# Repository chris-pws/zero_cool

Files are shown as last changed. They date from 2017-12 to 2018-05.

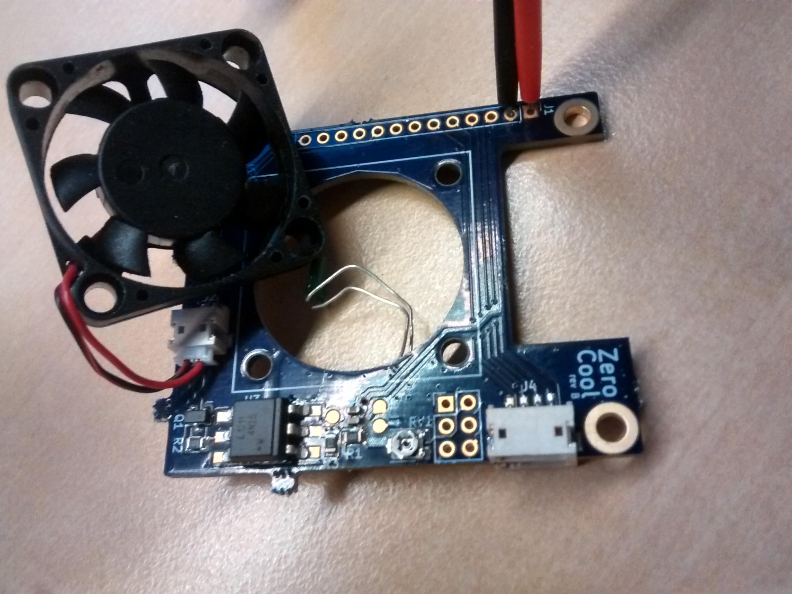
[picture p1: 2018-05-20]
IMG_20180520_031025.jpg

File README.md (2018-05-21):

# ZeroCool

Given that the Orange Pi Zero gets very hot when using all four cores and on-board wifi for any sustained period of time, I decided to create a fan controller that minimizes fan noise and respects the integrity of the wireless signal with respect to EMF noise. In keeping with the compact form factor of the Zero, this board shall mate securely with the SBC and cooling fan, and provide ready access to the H2+'s additional USB ports.

## Project notes

[Initial mechanical measurement and layout notes](https://github.com/cms-/zero_cool/blob/master/003.jpg)

[Rev B assembly and bring-up](https://github.com/cms-/zero_cool/blob/master/IMG_20180520_031025.jpg)

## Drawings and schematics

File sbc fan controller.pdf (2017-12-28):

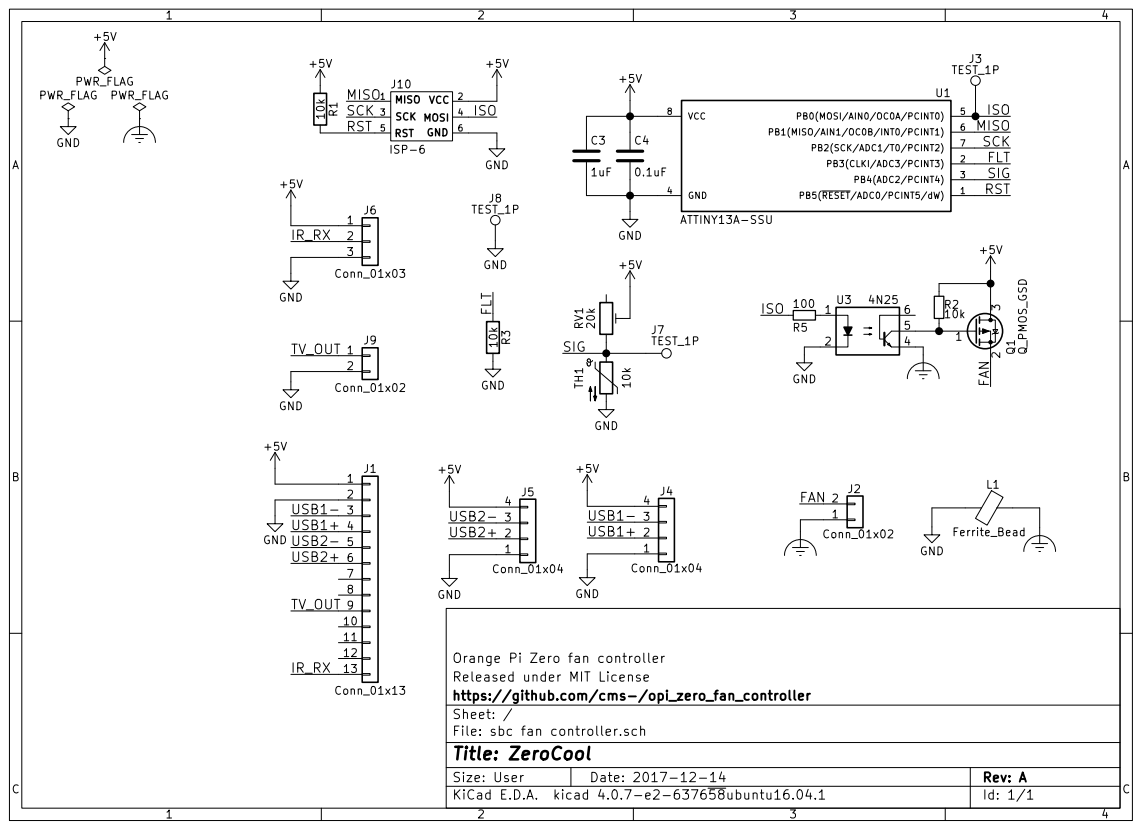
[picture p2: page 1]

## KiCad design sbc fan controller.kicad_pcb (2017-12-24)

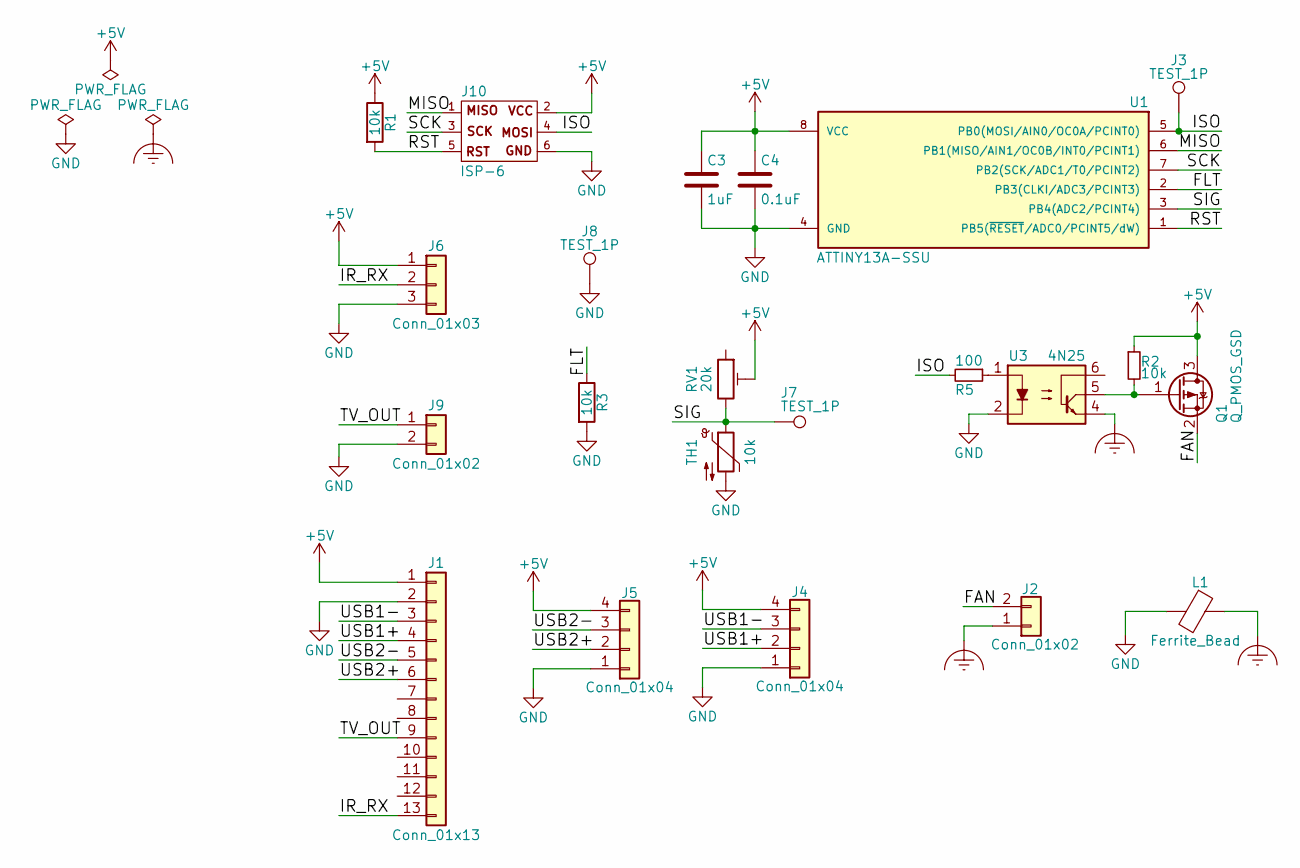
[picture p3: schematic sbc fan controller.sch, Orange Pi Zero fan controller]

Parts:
C3: 1uF; C_0603
C4: 0.1uF; C_0603
J1: Conn_01x13; Pin_Header_Straight_1x13_Pitch2.54mm
J2, J9: Conn_01x02; JST_ZH_SM02B-ZRSS-TB_1x02_P1.50mm_Horizontal
J3, J7, J8: TEST_1P; Measurement_Point_Round-SMD-Pad_Small
J4, J5: Conn_01x04; JST_ZH_SM04B-ZRSS-TB_1x04_P1.50mm_Horizontal
J6: Conn_01x03; JST_ZH_SM03B-ZRSS-TB_1x03_P1.50mm_Horizontal
J10: ISP-6; Pin_Header_Straight_2x03_Pitch2.54mm
L1: Ferrite_Bead; R_0805
Q1: Q_PMOS_GSD; SOT-23
R1, R2, R3: 10k; R_0805
R5: 100; R_0805
RV1: 20k; TC33
TH1: 10k; JST_ZH_SM02B-ZRSS-TB_1x02_P1.50mm_Horizontal
U1: ATTINY13A-SSU; SOIC-8_3.9x4.9mm_Pitch1.27mm
U3: 4N25; SO-6_4.4x3.6mm_Pitch1.27mm

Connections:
+5V: C3.1, C4.1, J1.1, J4.4, J5.4, J6.1, J10.2, Q1.3 (D), R1.1, R2.1, RV1.2, U1.8 (VCC)
/FAN: J2.2, Q1.2 (S)
/FLT: R3.1, U1.2 (PB3(CLKI/ADC3/PCINT3))
/IR_RX: J1.13, J6.2
/ISO: J3.1, J10.4, R5.2, U1.5 (PB0(MOSI/AIN0/OC0A/PCINT0))
/MISO: J10.1, U1.6 (PB1(MISO/AIN1/OC0B/INT0/PCINT1))
/RST: J10.5, R1.2, U1.1 (PB5(~RESET~/ADC0/PCINT5/dW))
/SCK: J10.3, U1.7 (PB2(SCK/ADC1/T0/PCINT2))
/SIG: J7.1, RV1.3, TH1.1, U1.3 (PB4(ADC2/PCINT4))
/TV_OUT: J1.9, J9.1
/USB1+: J1.4, J4.2
/USB1-: J1.3, J4.3
/USB2+: J1.6, J5.2
/USB2-: J1.5, J5.3
Earth_Clean: J2.1, L1.1, U3.4
GND: C3.2, C4.2, J1.2, J4.1, J5.1, J6.3, J8.1, J9.2, J10.6, L1.2, R3.2, TH1.2, U1.4 (GND), U3.2
unnamed: Q1.1 (G), R2.2, U3.5
unnamed: R5.1, U3.1

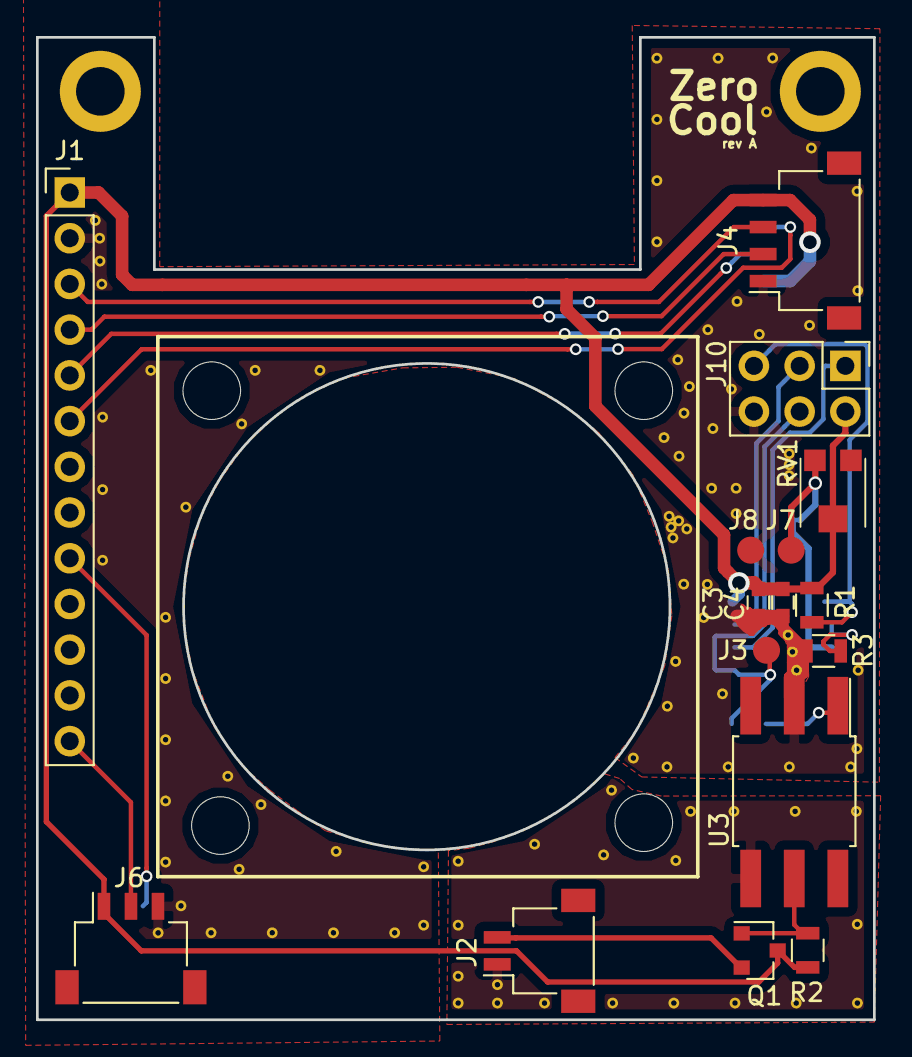
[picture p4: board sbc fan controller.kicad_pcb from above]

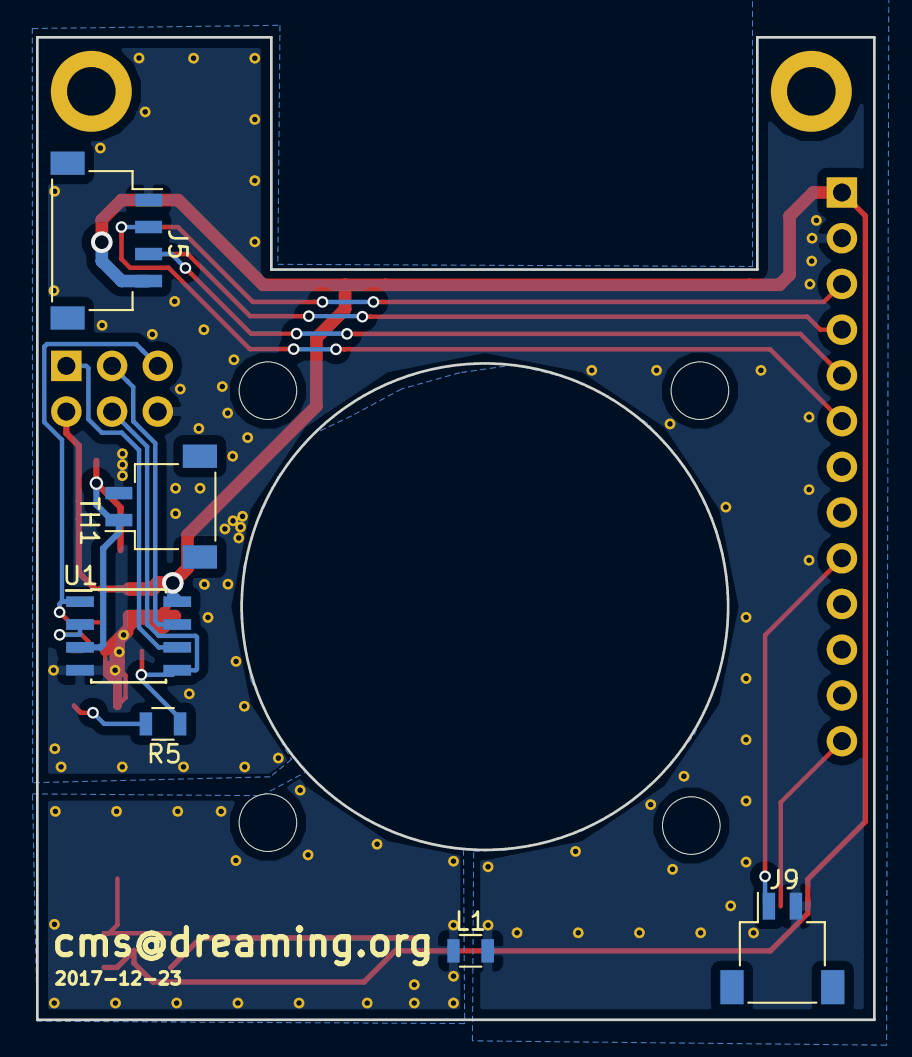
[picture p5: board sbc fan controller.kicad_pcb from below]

Board: 2 copper layers, 46.5 x 54.6 mm, 22 parts (6 on the bottom side), 18 nets.

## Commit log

2017-12-14 Update schematic PDF
2017-12-14 Auto stash before merge of "master" and "opi_zero_fan_controller/master"
    [sbc fan controller.sch]
2017-12-14 Correcting references for consistency
    Also added RCA coax connector, although this may not fit on the final board.
    [sbc fan controller.sch]
2017-12-14 Corrected non-inverting signal input network names
    [sbc fan controller.sch]
2017-12-14 Minor layout corrections
    [sbc fan controller.sch]
2017-12-15 Initial layout of devices
    [sbc fan controller.kicad_pcb]
2017-12-18 Simplified design, dropped amp; added isolated ground
    After testing the dual amp circuit against a simple voltage divider, ADC yields enough resolution to discern heat levels in order to accommodate a look up table for fan speed. Isolated ground plane f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
    [sbc fan controller.kicad_pcb, sbc fan controller.sch]
2017-12-24 Final layout
    Simplified layout and tested each footprint with a hard copy layout actual parts.
    [sbc fan controller.kicad_pcb, sbc fan controller.sch]
2017-12-28 Final schematic
    [sbc fan controller.sch]
2017-12-28 Final schematic update
    Reflects simplification of analog portion
2018-05-20 Rev B bring-up and testing
    Tested OK. Functions as suspected. PWM frequency needs to be lowered outside of human hearing.

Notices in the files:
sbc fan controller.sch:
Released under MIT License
